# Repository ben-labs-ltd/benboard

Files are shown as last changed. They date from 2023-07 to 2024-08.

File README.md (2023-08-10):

# BenBoard

benboard logo
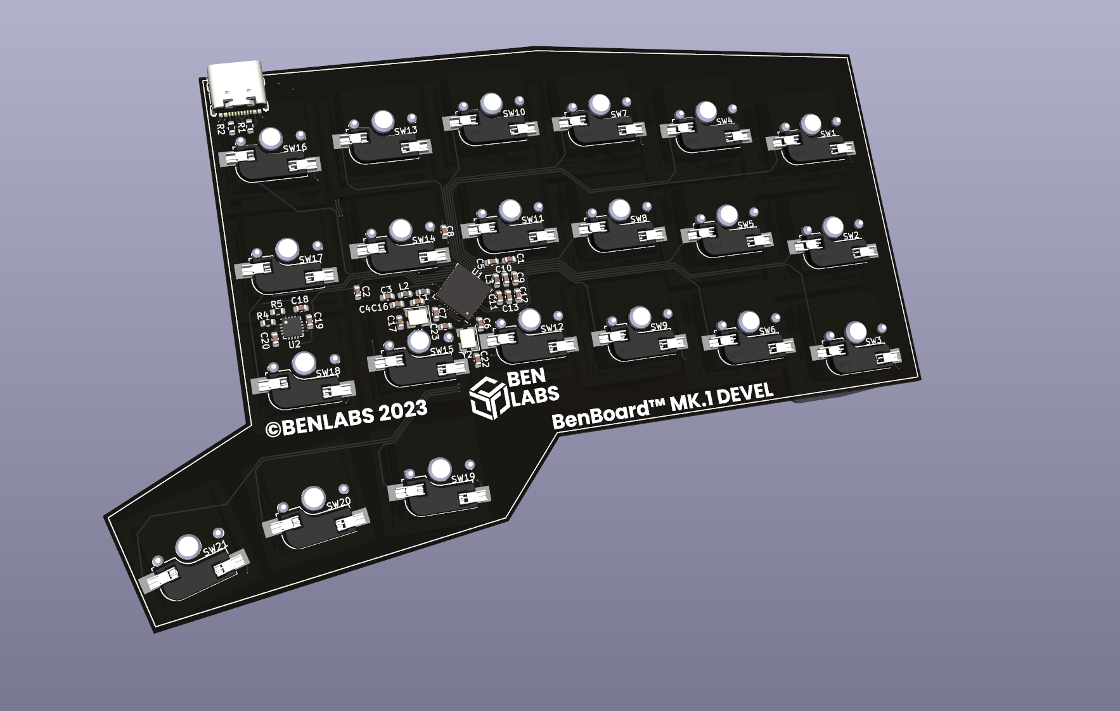
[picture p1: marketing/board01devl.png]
benboard svg


The highly customisable, open source, premium 42 key ergo mechanical keyboard

Show your interest at https://ben-labs.co.uk

## Features

- Reduced layout 42 key split keyboard
- Cherry MX hotswap compatable (any 3 or 5 pin)
- Fully wireless (BLE)
- Month-long battery life with the low power NRF52840
- Out of the box ZMK Support
- Supports [VIK](https://github.com/sadekbaroudi/vik) (on both sides!)
- Unibody case that has been verified to be CNC'able

## Contribution

[ ] TODO

## VIK Certification

| Category | Classification | Response |
| ---  | --- | --- |
| FPC connector | Required | :heavy_check_mark: |
| Breakout pins | Recommended | :x: |
| Supplies: SPI | Required | :heavy_check_mark: |
| Supplies: I2C | Required | :heavy_check_mark: |
| I2C on main PCB | Discouraged | :x: |
| I2C pull ups | Informative | :x: |
| Supplies: RGB | Required | :heavy_check_mark: |
| Supplies: Extra GPIO 1 | Required | :heavy_check_mark: (Analogue and Digital) |
| Supplies: Extra GPIO 2 | Required | :heavy_check_mark: (Analogue and Digital) |

THIS IS A WORK IN PROGRESS, ANY FEATURES LISTED ARE PURELY IN PROGRESS

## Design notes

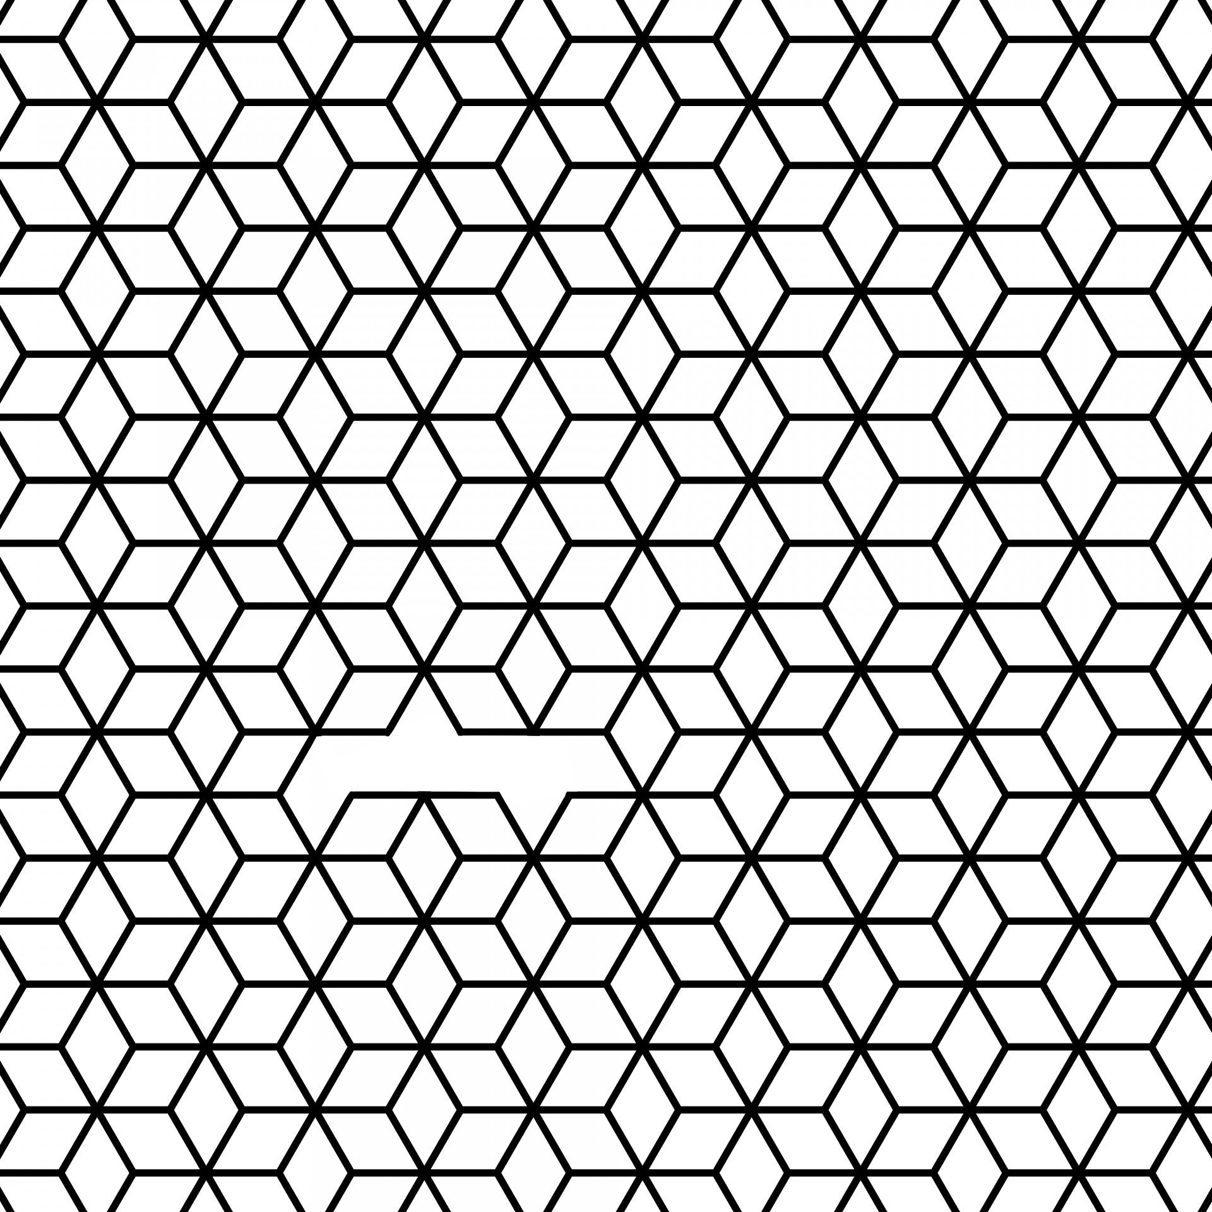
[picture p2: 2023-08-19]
marketing/hex-pattern.jpg

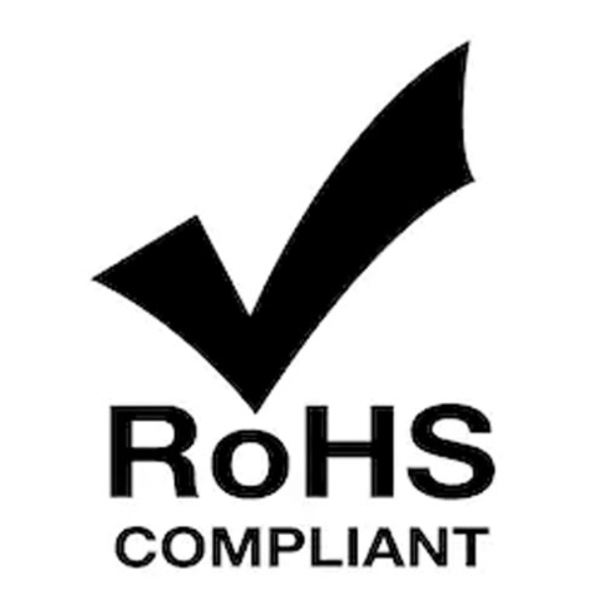
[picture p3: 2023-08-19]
marketing/RoHS.png

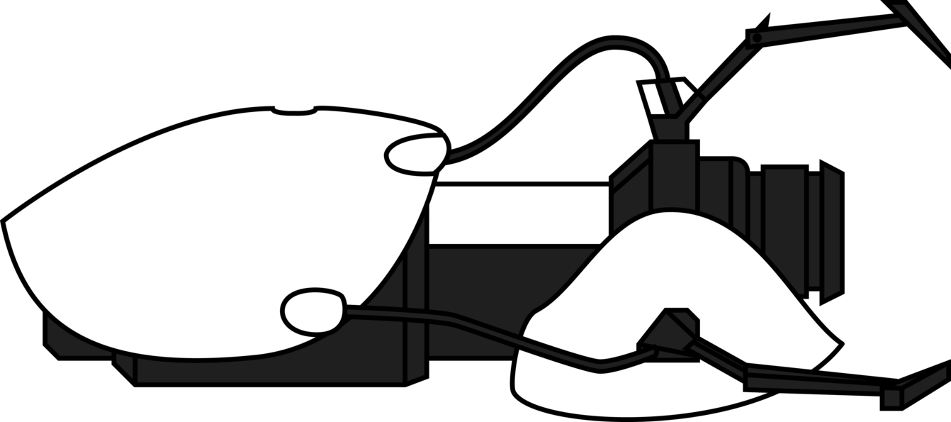
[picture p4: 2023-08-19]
marketing/portal.png

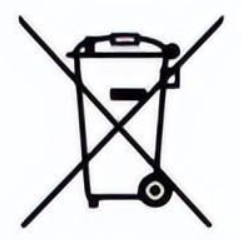
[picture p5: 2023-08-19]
marketing/no_bin.png

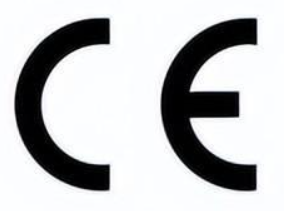
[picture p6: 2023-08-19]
marketing/ce.png

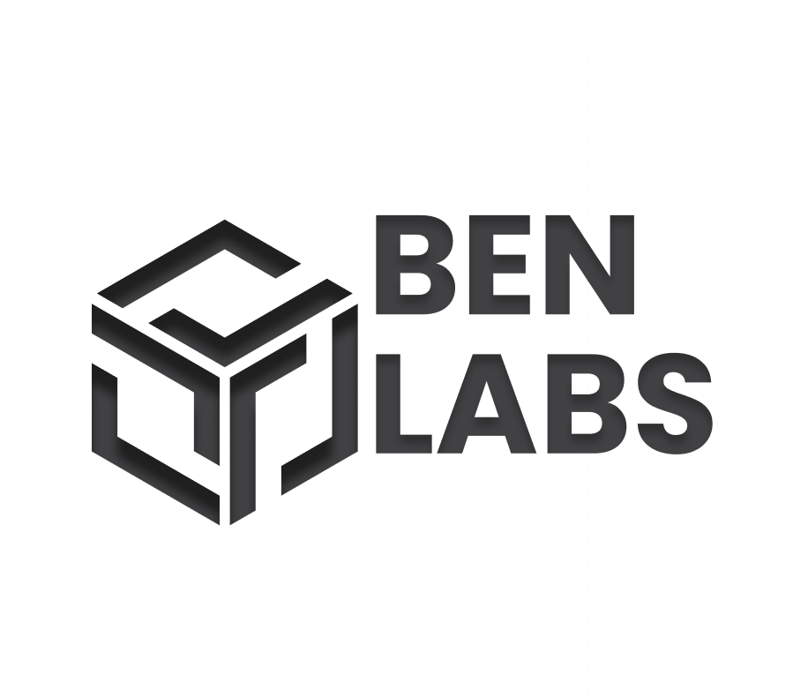
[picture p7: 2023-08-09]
marketing/ben labs.png

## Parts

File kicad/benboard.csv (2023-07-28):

Source: | /home/benk/dprog/active/benboard/kicad/benboard.kicad_sch
Date: | Thu 27 Jul 2023 17:12:29 BST
Tool: | Eeschema 7.0.6
Generator: | /usr/share/kicad/plugins/bom_csv_grouped_by_value_with_fp.py
Component Count: | 59
Ref | Qnty | Value | Cmp name | Footprint | Description | Vendor | DNP
C1, C2, C5, C9, C19, C20 | 6 | 4.7uF | C | Capacitor_SMD:C_0603_1608Metric | Unpolarized capacitor
C3, C13, C18 | 3 | 1uF | C | Capacitor_SMD:C_0603_1608Metric | Unpolarized capacitor
C4 | 1 | 47nF | C | Capacitor_SMD:C_0603_1608Metric | Unpolarized capacitor
C6, C10, C11, C12 | 4 | 100nF | C | Capacitor_SMD:C_0603_1608Metric | Unpolarized capacitor
C7 | 1 | 100pF | C | Capacitor_SMD:C_0603_1608Metric | Unpolarized capacitor
C8 | 1 | 820pF | C | Capacitor_SMD:C_0603_1608Metric | Unpolarized capacitor
C14 | 1 | 0.5pF | C | Capacitor_SMD:C_0603_1608Metric | Unpolarized capacitor
C16, C17, C22, C23 | 4 | 12pF | C | Capacitor_SMD:C_0603_1608Metric | Unpolarized capacitor
C21 | 1 | 0.8pF | C | Capacitor_SMD:C_0603_1608Metric | Unpolarized capacitor
J1 | 1 | USB_C_Receptacle_USB2.0 | USB_C_Receptacle_USB2.0 | Connector_USB:USB_C_Receptacle_G-Switch_GT-USB-7010ASV | USB 2.0-only Type-C Receptacle connector
J2 | 1 | ~ | vik-keyboard-connector
L1, L3 | 2 | 10uH | L | Inductor_SMD:L_0603_1608Metric | Inductor
L2 | 1 | 15nH | L | Inductor_SMD:L_0603_1608Metric | Inductor
L4 | 1 | 4.1nH | L | Inductor_SMD:L_0603_1608Metric | Inductor
R1, R2 | 2 | 5.1k | R | Resistor_SMD:R_0603_1608Metric | Resistor
R3, R4, R5 | 3 | 10k | R | Resistor_SMD:R_0603_1608Metric | Resistor
RED1 | 1 | LED | LED | LED_SMD:LED_0805_2012Metric | Light emitting diode
SW1, SW2, SW3, SW4, SW5, SW6, SW7, SW8, SW9, SW10, SW11, SW12, SW13, SW14, SW15, SW16, SW17, SW18, SW19, SW20, SW21 | 21 | SW_Push | SW_Push | keyswitches:Kailh_socket_MX | Push button switch, generic, two pins
U1 | 1 | nRF52840 | nRF52840 | Package_DFN_QFN:Nordic_AQFN-73-1EP_7x7mm_P0.5mm | Multiprotocol BLE/ANT/2.4 GHz/802.15.4 Cortex-M4F SoC, AQFN-73
U2 | 1 | BQ24075RGT | BQ24075RGT | Package_DFN_QFN:VQFN-16-1EP_3x3mm_P0.5mm_EP1.6x1.6mm | USB-Friendly Li-Ion Battery Charger and Power-Path Management, VQFN-16
Y1 | 1 | 32MHz | Crystal_GND2 | Crystal:Crystal_SMD_SeikoEpson_FA238V-4Pin_3.2x2.5mm | Three pin crystal, GND on pin 2
Y2 | 1 | 32.768kHz | Crystal_GND2 | Crystal:Crystal_SMD_SeikoEpson_FA238V-4Pin_3.2x2.5mm | Three pin crystal, GND on pin 2

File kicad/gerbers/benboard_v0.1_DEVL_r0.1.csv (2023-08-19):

Id | Designator | Footprint | Quantity | Designation | Supplier and ref
1 | SW22 | SW_CuK_OS102011MA1QN1_SPDT_Angled | 1 | SW_DPDT
2 | TP18,TP17,TP16,TP15,TP14,TP13,TP12,TP11,TP10,TP9,TP8,TP7,TP6,TP5,TP4,TP3,TP2,TP1 | TestPoint_Pad_D1.0mm | 18 | Probe
3 | R4,R3,R1 | R_0603_1608Metric | 3 | 47k
4 | SW16,SW6,SW8,SW5,SW18,SW10,SW4,SW14,SW9,SW7,SW11,SW19,SW2,SW15,SW21,SW1,SW20,SW3,SW12,SW13,SW17 | Kailh_socket_MX | 21 | SW_Push
5 | D2,D3,D1 | LED_0805_2012Metric | 3 | LED
6 | J4 | JST_EH_B2B-EH-A_1x02_P2.50mm_Vertical | 1 | Conn_01x02_Pin
7 | C21 | C_0603_1608Metric | 1 | 0.8pF
8 | C26,C10,C24,C11,C12,C6 | C_0603_1608Metric | 6 | 100nF
9 | C19,C20,C25,C18 | C_0603_1608Metric | 4 | 10uF
10 | C1,C3,C13,C15 | C_0603_1608Metric | 4 | 1uF
11 | J2 | vik-keyboard-connector-horizontal | 1 | ~
12 | L7,L6 | L_0603_1608Metric | 2 | 2.2uH
13 | C2,C5,C9 | C_0603_1608Metric | 3 | 4.7uF
14 | C7 | C_0603_1608Metric | 1 | 100pF
15 | C16,C22,C17,C23 | C_0603_1608Metric | 4 | 12pF
16 | U2 | Texas_R-PDSO-G6 | 1 | TPS61222DCK
17 | L5 | L_0603_1608Metric | 1 | 4.7uH
18 | C14 | C_0603_1608Metric | 1 | 0.5pF
19 | C27 | C_0603_1608Metric | 1 | 2.2uF
20 | J1 | USB_C_Receptacle_G-Switch_GT-USB-7010ASV | 1 | USB_C_Receptacle_USB2.0
21 | Y2 | Crystal_SMD_SeikoEpson_FA238V-4Pin_3.2x2.5mm | 1 | 32.768kHz
22 | D4 | SOT-143 | 1 | PRTR5V0U2X
23 | Y1 | Crystal_SMD_SeikoEpson_FA238V-4Pin_3.2x2.5mm | 1 | 32MHz
24 | J5 | U.FL_Hirose_U.FL-R-SMT-1_Vertical | 1 | Conn_Coaxial
25 | C8 | C_0603_1608Metric | 1 | 820pF
26 | L2 | L_0603_1608Metric | 1 | 15nH
27 | L4 | L_0603_1608Metric | 1 | 4.1nH
28 | C4 | C_0603_1608Metric | 1 | 47nF
29 | L3,L1 | L_0603_1608Metric | 2 | 10uH
30 | U3 | QFN-32-1EP_5x5mm_P0.5mm_EP3.6x3.6mm_ThermalVias | 1 | nPM1300-QEXX
31 | U1 | Nordic_AQFN-73-1EP_7x7mm_P0.5mm | 1 | nRF52840
32 | R2 | R_0603_1608Metric | 1 | 250k

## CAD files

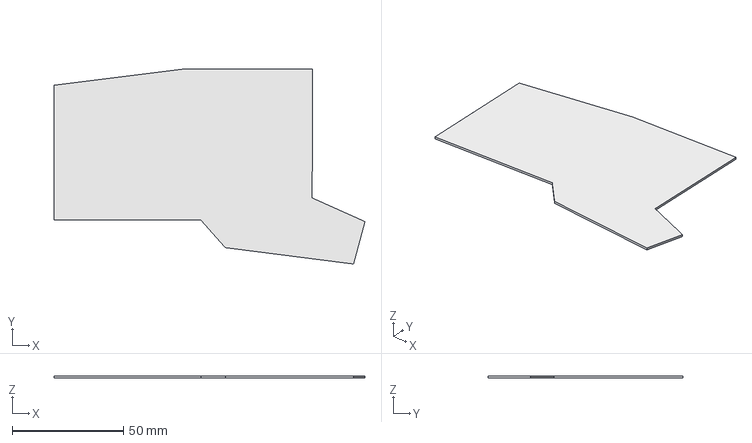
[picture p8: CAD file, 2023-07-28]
cad/case.FCStd
139.8 x 87.7 x 1.00 mm

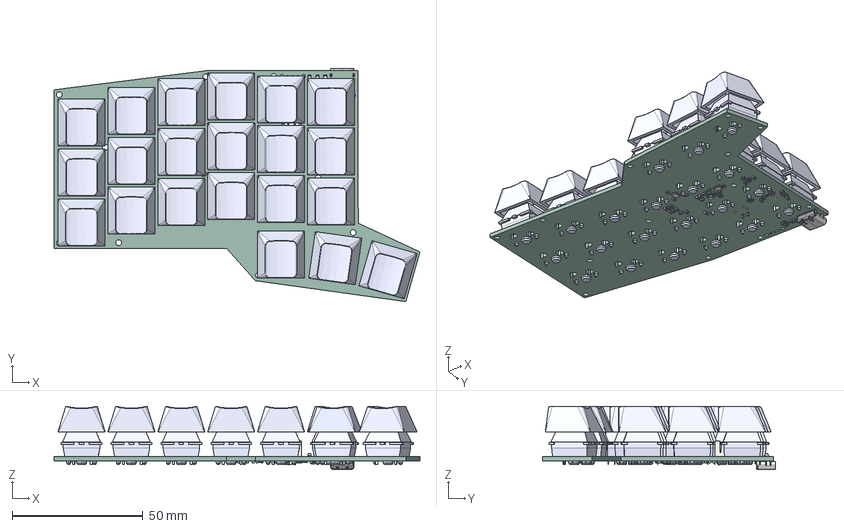
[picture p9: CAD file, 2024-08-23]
kicad/benboard.step
140.0 x 89.2 x 24.3 mm
09EDEC74-1FCF-4F9F-8741-5FB57C5DD93E x 21
374C6C5B-C079-40F1-8654-6178DD41A55E x 21
LED_0805_2012Metric x 3
JST_B2B_EH_A
C_0603_1608Metric x 27
L_0603_1608Metric x 7
SOT_363_SC_70_6
R_0603_1608Metric x 4
USB_C_Receptacle_16P_TopMnt_Horizontal_GCT_USB4105-xx-A
Crystal_SMD_SeikoEpson_FA238V-4Pin_3.2x2.5mm x 2
SOT_143
U.FL_Hirose_U.FL-R-SMT-1_Vertical
benboard_PCB

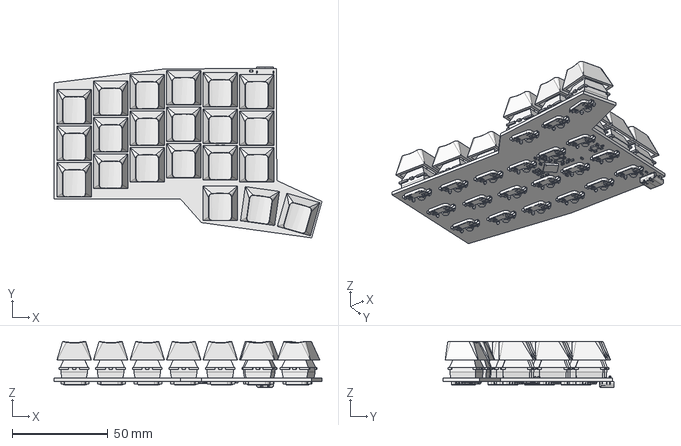
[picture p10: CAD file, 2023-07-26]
cad/benboard.FCStd
140.0 x 89.2 x 24.3 mm

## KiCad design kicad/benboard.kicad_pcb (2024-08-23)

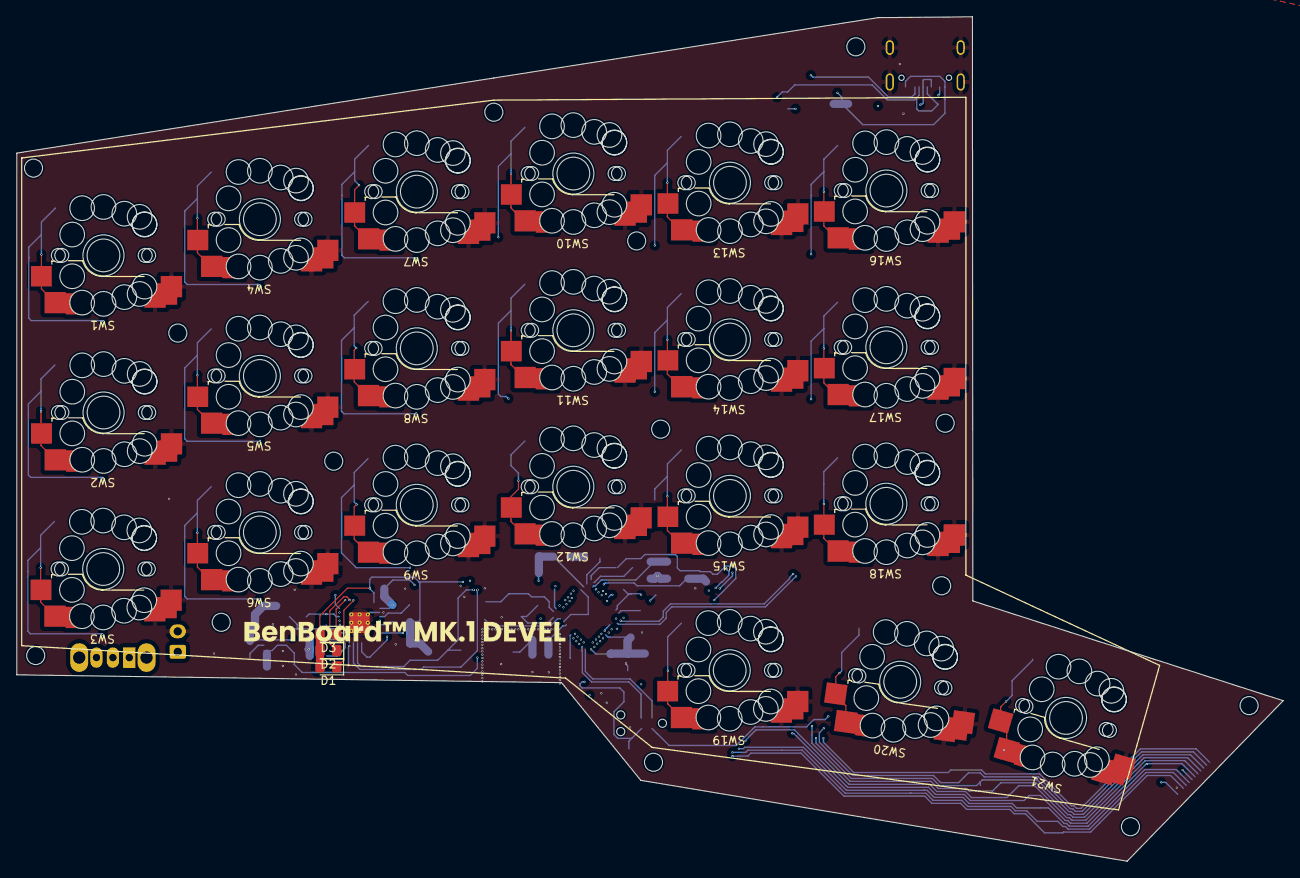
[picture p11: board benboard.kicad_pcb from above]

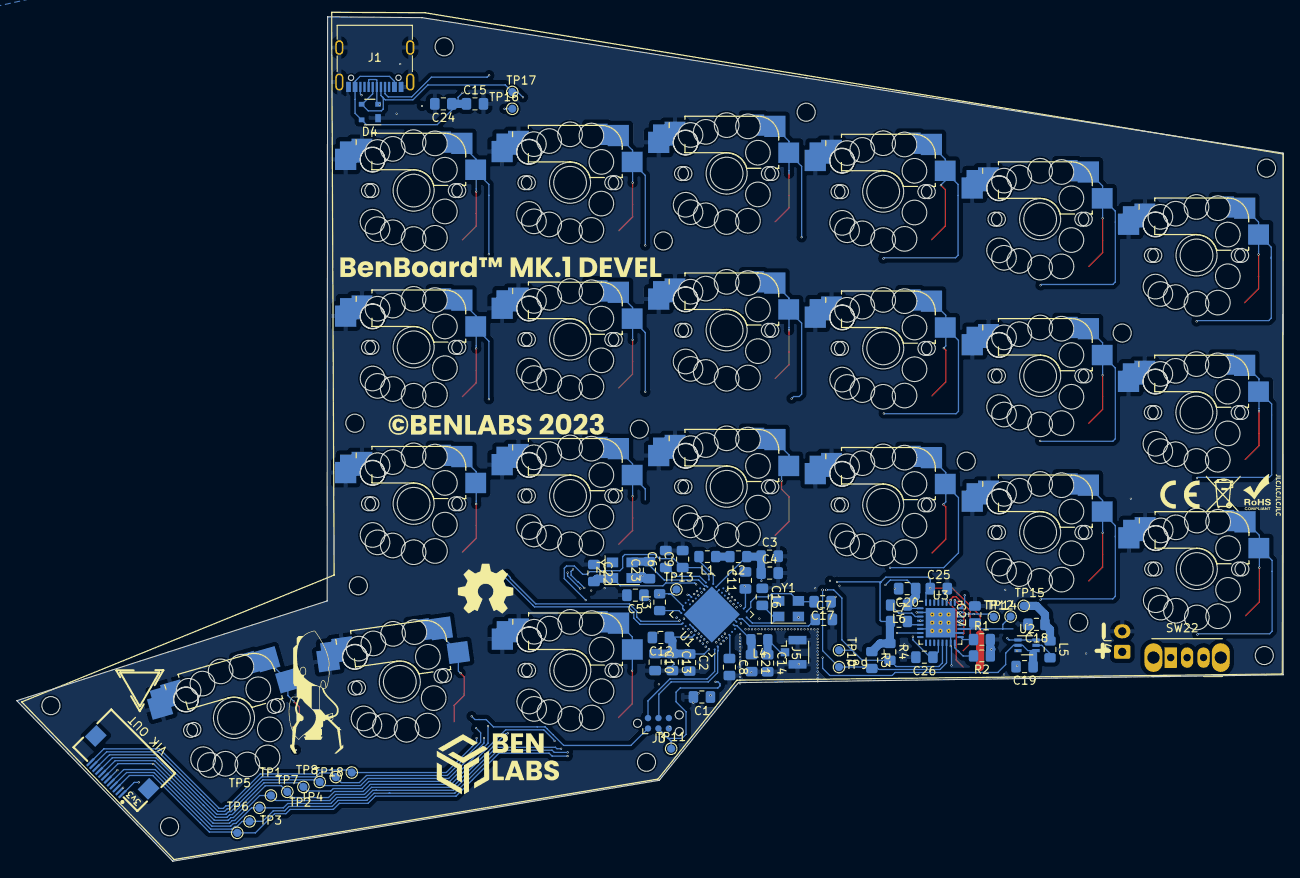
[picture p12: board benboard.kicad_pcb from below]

Board: 4 copper layers, 154.2 x 102.9 mm, 92 parts (67 on the bottom side), 70 nets.

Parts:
C1, C3, C13, C15: 1uF; C_0805_2012Metric_Pad1.18x1.45mm_HandSolder
C2, C5, C9: 4.7uF; C_0805_2012Metric_Pad1.18x1.45mm_HandSolder
C4: 47nF; C_0805_2012Metric_Pad1.18x1.45mm_HandSolder
C6, C10, C11, C12, C24, C26: 100nF; C_0805_2012Metric_Pad1.18x1.45mm_HandSolder
C7: 100pF; C_0805_2012Metric_Pad1.18x1.45mm_HandSolder
C8: 820pF; C_0805_2012Metric_Pad1.18x1.45mm_HandSolder
C14: 0.5pF; C_0805_2012Metric_Pad1.18x1.45mm_HandSolder
C16, C17, C22, C23: 12pF; C_0805_2012Metric_Pad1.18x1.45mm_HandSolder
C18, C19, C20, C25: 10uF; C_0805_2012Metric_Pad1.18x1.45mm_HandSolder
C21: 0.8pF; C_0805_2012Metric_Pad1.18x1.45mm_HandSolder
C27: 2.2uF; C_0805_2012Metric_Pad1.18x1.45mm_HandSolder
D1, D2, D3: LED; LED_0805_2012Metric_Pad1.15x1.40mm_HandSolder
D4: PRTR5V0U2X; SOT-143
J1: USB_C_Receptacle_USB2.0; USB_C_Receptacle_G-Switch_GT-USB-7010ASV
J2: vik-keyboard-connector-horizontal
J3: Conn_ARM_SWD_TagConnect_TC2030-NL; Tag-Connect_TC2030-IDC-NL_2x03_P1.27mm_Vertical
J4: Conn_01x02_Pin; JST_EH_B2B-EH-A_1x02_P2.50mm_Vertical
J5: Conn_Coaxial; U.FL_Hirose_U.FL-R-SMT-1_Vertical
L1, L3: 10uH; L_0805_2012Metric_Pad1.15x1.40mm_HandSolder
L2: 15nH; L_0805_2012Metric_Pad1.15x1.40mm_HandSolder
L4: 4.1nH; L_0805_2012Metric_Pad1.15x1.40mm_HandSolder
L5: 4.7uH; L_0805_2012Metric_Pad1.15x1.40mm_HandSolder
L6, L7: 2.2uH; L_0805_2012Metric_Pad1.15x1.40mm_HandSolder
R1, R3, R4: 47k; L_0805_2012Metric_Pad1.15x1.40mm_HandSolder
R2: 250k; L_0805_2012Metric_Pad1.15x1.40mm_HandSolder
SW1, SW2, SW3, SW4, SW5, SW6, SW7, SW8, SW9, SW10, SW11, SW12, SW13, SW14, SW15, SW16, SW17, SW18, SW19, SW20, SW21: SW_Push; gateron-ks27-choc-v1-mx-hotswap-reversible
SW22: SW_DPDT; SW_CuK_OS102011MA1QN1_SPDT_Angled
TP1, TP2, TP3, TP4, TP5, TP6, TP7, TP8, TP9, TP10, TP11, TP12, TP13, TP14, TP15, TP16, TP17, TP18: Probe; TestPoint_Pad_D1.0mm
U1: nRF52840; Nordic_AQFN-73-1EP_7x7mm_P0.5mm
U2: TPS61222DCK; Texas_R-PDSO-G6
U3: nPM1300-QEXX; QFN-32-1EP_5x5mm_P0.5mm_EP3.6x3.6mm_ThermalVias
Y1: 32MHz; Crystal_SMD_SeikoEpson_FA238V-4Pin_3.2x2.5mm
Y2: 32.768kHz; Crystal_SMD_SeikoEpson_FA238V-4Pin_3.2x2.5mm

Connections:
+3V3: C25.1, D1.2 (A), D2.2 (A), D3.2 (A), J2.1 (3V3), J3.1 (VCC), L7.1, R3.1, R4.1, U3.32 (VOUT2)
+5V: C19.1, J2.6 (5V), U2.2 (FB), U2.4 (VOUT)
CC1: J1.A5 (CC1), U3.23 (CC1)
CC2: J1.B5 (CC2), U3.24 (CC2)
D+: D4.2 (I/O1), J1.A6 (D+), J1.B6 (D+), TP16.1, U1.AD6 (D+)
D-: D4.3 (I/O2), J1.A7 (D-), J1.B7 (D-), TP17.1, U1.AD4 (D-)
GND: C1.2, C2.2, C3.2, C4.2, C5.2, C6.2, C7.2, C8.2, C9.2, C10.2, C11.2, C12.2, C13.2, C14.2, C15.2, C16.1, C17.1, C18.2, C19.2, C20.2, C21.2, C22.1, C23.1, C24.2, C25.2, C26.2, C27.2, D4.1 (GND), J1.A1 (GND), J1.A12 (GND), J1.B1 (GND), J1.B12 (GND), J1.S1 (SHIELD), J2.2 (GND), J3.5 (GND), J4.2, J5.2 (Ext), R1.2, R2.1, SW1.1, SW2.1, SW3.1, SW4.1, SW5.1, SW6.1, SW7.1, SW8.1, SW9.1, SW10.1, SW11.1, SW12.1, SW13.1, SW14.1, SW15.1, SW16.1, SW17.1, SW18.1, SW19.1, SW20.1, SW21.1, U1.B7 (VSS), U1.EP (VSS), U1.F23 (VSS_PA), U2.3 (GND), U3.2 (PVSS1), U3.6 (PVSS2), U3.15 (SHPHLD), U3.18 (NTC), U3.33 (AVSS), Y1.2, Y2.2
MISO: J2.11 (MISO), TP8.1, U1.A14 (P1.15)
MOSI: J2.8 (MOSI), TP7.1, U1.A20 (P1.10)
unnamed: D1.1 (K), U3.27 (LED2)
unnamed: D2.1 (K), U3.26 (LED1)
unnamed: D3.1 (K), U3.25 (LED0)
unnamed: J4.1, SW22.3 (C)
unnamed: C14.1, J5.1 (In), L4.1
unnamed: L1.1, L2.2
unnamed: C21.1, L4.2, U1.H23 (ANT)
unnamed: L1.2, U1.B3 (DCC)
unnamed: L3.1, U1.AB2 (DCCH)
unnamed: C6.1, U1.C1 (DEC1)
unnamed: C7.1, U1.D23 (DEC3)
unnamed: C3.1, C4.1, L2.1, U1.B5 (DEC4), U1.E24 (DEC6)
unnamed: C8.1, U1.N24 (DEC5)
unnamed: C5.1, U1.AC5 (DECUSB)
unnamed: C16.2, U1.B24 (XC1), Y1.1
unnamed: C17.2, U1.A23 (XC2), Y1.3
unnamed: C23.2, U1.D2 (XL1/P0.00), Y2.3
unnamed: C22.2, U1.F2 (XL2/P0.01), Y2.1
unnamed: L5.2, U2.5 (L)
unnamed: L6.2, U3.3 (SW1)
unnamed: L7.2, U3.5 (SW2)
unnamed: R1.1, U3.17 (VSET1)
unnamed: R2.2, U3.16 (VSET2)
RST: J3.3 (~RESET), TP11.1, U1.AC9 (P0.14), U1.AC11 (P0.16), U1.AC13 (P0.18/~RESET), U3.7 (GPIO0)
SCK: R3.2, TP9.1, U1.K2 (AIN3/P0.05), U3.14 (SCL)
SCLK: J2.12 (SCLK), TP18.1, U1.A10 (AIN5/P0.29)
SDA: R4.2, TP10.1, U1.J1 (AIN2/P0.04), U3.13 (SDA)
SPICS: J2.10 (SPI_CS), TP4.1, U1.A16 (P1.13)
SW1: SW1.2, U1.L1 (P0.06)
SW2: SW2.2, U1.AC15 (P0.19)
SW3: SW3.2, U1.AC21 (P0.25)
SW4: SW4.2, U1.AD10 (P0.15)
SW5: SW5.2, U1.P2 (P1.08)
SW6: SW6.2, U1.AC19 (P0.23)
SW7: SW7.2, U1.AD12 (P0.17)
SW8: SW8.2, U1.N1 (P0.08)
SW9: SW9.2, U1.AC17 (P0.21)
SW10: SW10.2, U1.AD16 (P0.20)
SW11: SW11.2, U1.AD22 (TRACEDATA0/P1.00)
SW12: SW12.2, U1.R24 (P1.06)
SW13: SW13.2, U1.AD18 (P0.22)
SW14: SW14.2, U1.W24 (P1.02)
SW15: SW15.2, U1.Y23 (P1.01)
SW16: SW16.2, U1.AD20 (P0.24)
SW17: SW17.2, U1.U24 (P1.04)
SW18: SW18.2, U1.H2 (P0.27)
SW19: SW19.2, U1.P23 (P1.07)
SW20: SW20.2, U1.T23 (P1.05)
SW21: SW21.2, U1.V23 (P1.03)
SWDC: J3.4 (SWCLK), U1.AA24 (SWDCLK)
SWDI: J3.2 (SWDIO), U1.AC24 (SWDIO)
VBAT: C27.1, SW22.2 (B), TP14.1, U3.19 (VBAT)
VBUS_IN: C15.1, C24.1, D4.4 (VCC), J1.A4 (VBUS), J1.A9 (VBUS), J1.B4 (VBUS), J1.B9 (VBUS), U3.21 (VBUS)
VBUS_MAIN: C1.1, TP12.1, U1.AD2 (VBUS), U3.22 (VBUSOUT)
VDD_NRF: C2.1, C9.1, C10.1, C11.1, C12.1, C13.1, C20.1, C26.1, L3.2, L6.1, TP13.1, U1.A22 (VDD), U1.AD14 (VDD), U1.AD23 (VDD), U1.B1 (VDD), U1.W1 (VDD), U1.Y2 (VDDH), U3.1 (VOUT1), U3.12 (VDDIO)
VIK_A0: J2.7 (GPIO_AD1), TP1.1, U1.A12 (AIN0/P0.02)
VIK_A1: J2.9 (GPIO_AD2), TP2.1, U1.B13 (AIN1/P0.03)
VIK_RGB: J2.5 (RGB_LED_OUT), TP3.1, U1.B15 (P1.14)
VIK_SCL: J2.4 (SCL), TP5.1, U1.B17 (P1.12)
VIK_SDA: J2.3 (SDA), TP6.1, U1.B19 (P1.11)
VSYS: C18.1, L5.1, TP15.1, U2.1 (VIN), U2.6 (EN), U3.4 (PVDD), U3.20 (VSYS)

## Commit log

2023-07-26 Ben Labs LTD. Now owns the BenBoard
    [benboard-B_Cu.gbr, benboard-B_Mask.gbr, benboard-B_Paste.gbr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]
2023-07-28 more cad files as well as readme
    [benboard.csv, benboard.kicad_pcb, benboard.kicad_sch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]
2023-07-31 add vik
    [benboard.kicad_pcb, benboard.kicad_sch]
2023-08-09 add vik and SWD
    [benboard.kicad_pcb, benboard.kicad_sch]
2023-08-09 routes for some stuff
    [benboard.kicad_pcb, benboard.kicad_sch]
2023-08-09 VIK Compatible
    [benboard.kicad_pcb, benboard.kicad_sch]
2023-08-09 proper footprint
    [benboard.kicad_pcb, benboard.kicad_sch]
2023-08-17 minor changes, inc VIK compat
    [benboard.kicad_pcb, benboard.kicad_sch]
2023-08-17 this is so epic
    [benboard.kicad_pcb, benboard.kicad_sch]
2023-08-18 schematic basically done
    [benboard.kicad_sch]
2023-08-18 almost ready for prototype 0
    [benboard.kicad_pcb, benboard.kicad_sch]
2023-08-19 benboard v0.0 r0.1
    [benboard-B_Cu.gbl, benboard-B_Cu.gbr, benboard-B_Mask.gbr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]
2023-08-19 that's it now i SWEAR
    [benboard-B_Cu.gbl, benboard-B_Mask.gbs, benboard-B_Paste.gbp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]
2024-08-23 new revision
    [benboard.kicad_pcb, benboard.step]
